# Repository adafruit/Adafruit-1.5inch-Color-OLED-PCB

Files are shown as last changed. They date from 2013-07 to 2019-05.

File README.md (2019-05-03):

# PCB for the Adafruit 1.5" Color OLED display breakout board

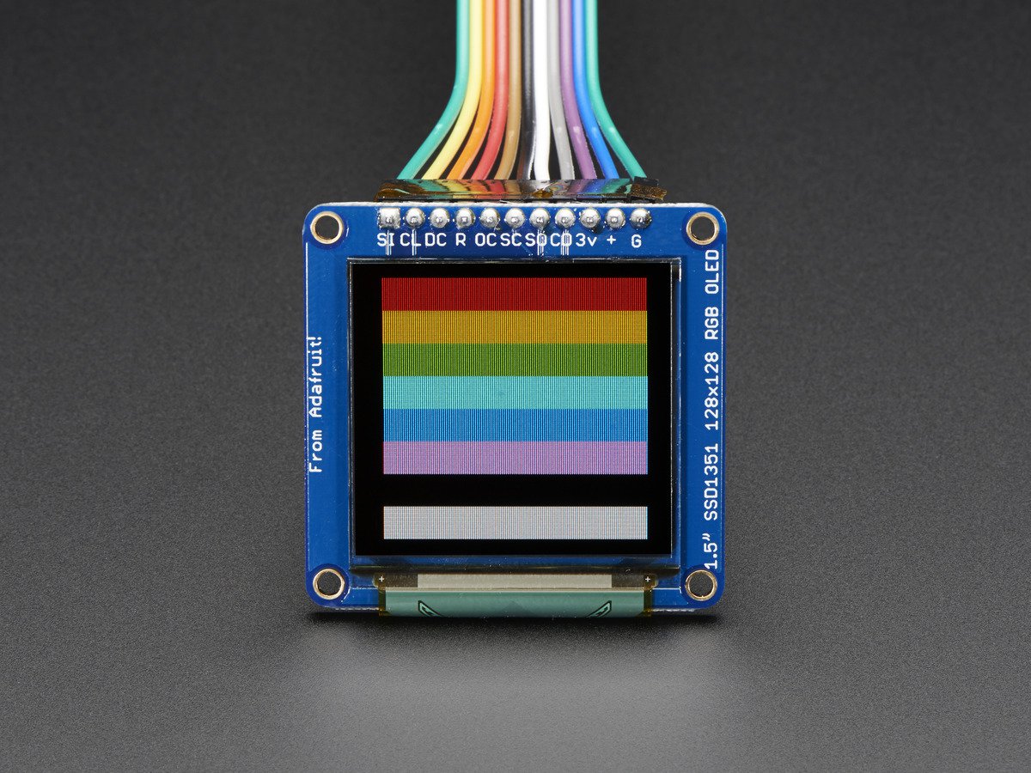
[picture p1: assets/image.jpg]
<a href="http://www.adafruit.com/products/1431"><br/>Click here to purchase one from the Adafruit shop</a>

This is the PCB for the Adafruit 1.5" Color OLED display breakout board
Format is EagleCAD schematic and board layout

We love our black and white monochrome displays but we also like to dabble with some color now and then. Our big 1.5" color OLED displays are perfect when you need a small display with vivid, high-contrast 16-bit color. The visible portion of the OLED measures 1.5" diagonal and contains 128x128 RGB pixels, each one made of red, green and blue OLEDs. Each pixel can be set with 16-bits of resolution for a large range of colors. Because the display uses OLEDs, there is no backlight, and the contrast is very high (black is really black). We picked this display for its excellent color, this is the nicest mini OLED we could find!

This OLED uses the SSD1351 driver chip, which manages the display. You can talk to the driver chip using 4-wire write-only SPI (clock, data, chip select, data/command and an optional reset pin). Included on the fully assembled breakout is the OLED display and a small boost converter (required for providing 12V to the OLED) and a microSD card holder. This design includes built-in logic level shifting so you can use it with 3-5VDC power and logic levels. Our example code shows how to read a bitmap from the uSD card and display it all via SPI.

Of course, we wouldn't just leave you with a datasheet and a "good luck!" - [we've written a full open source graphics library that can draw pixels, lines, rectangles, circles, text and bitmaps as well as example code](https://github.com/adafruit/Adafruit-SSD1351-library). The code is written for Arduino but can be easily ported to your favorite microcontroller! We do not have a detailed wiring tutorial at this time, but if you follow the example code wiring it should work just fine.

## License

Adafruit invests time and resources providing this open source design, 
please support Adafruit and open-source hardware by purchasing 
products from Adafruit!

Designed by Adafruit Industries.  
Creative Commons Attribution, Share-Alike license, check license.txt for more information
All text above must be included in any redistribution

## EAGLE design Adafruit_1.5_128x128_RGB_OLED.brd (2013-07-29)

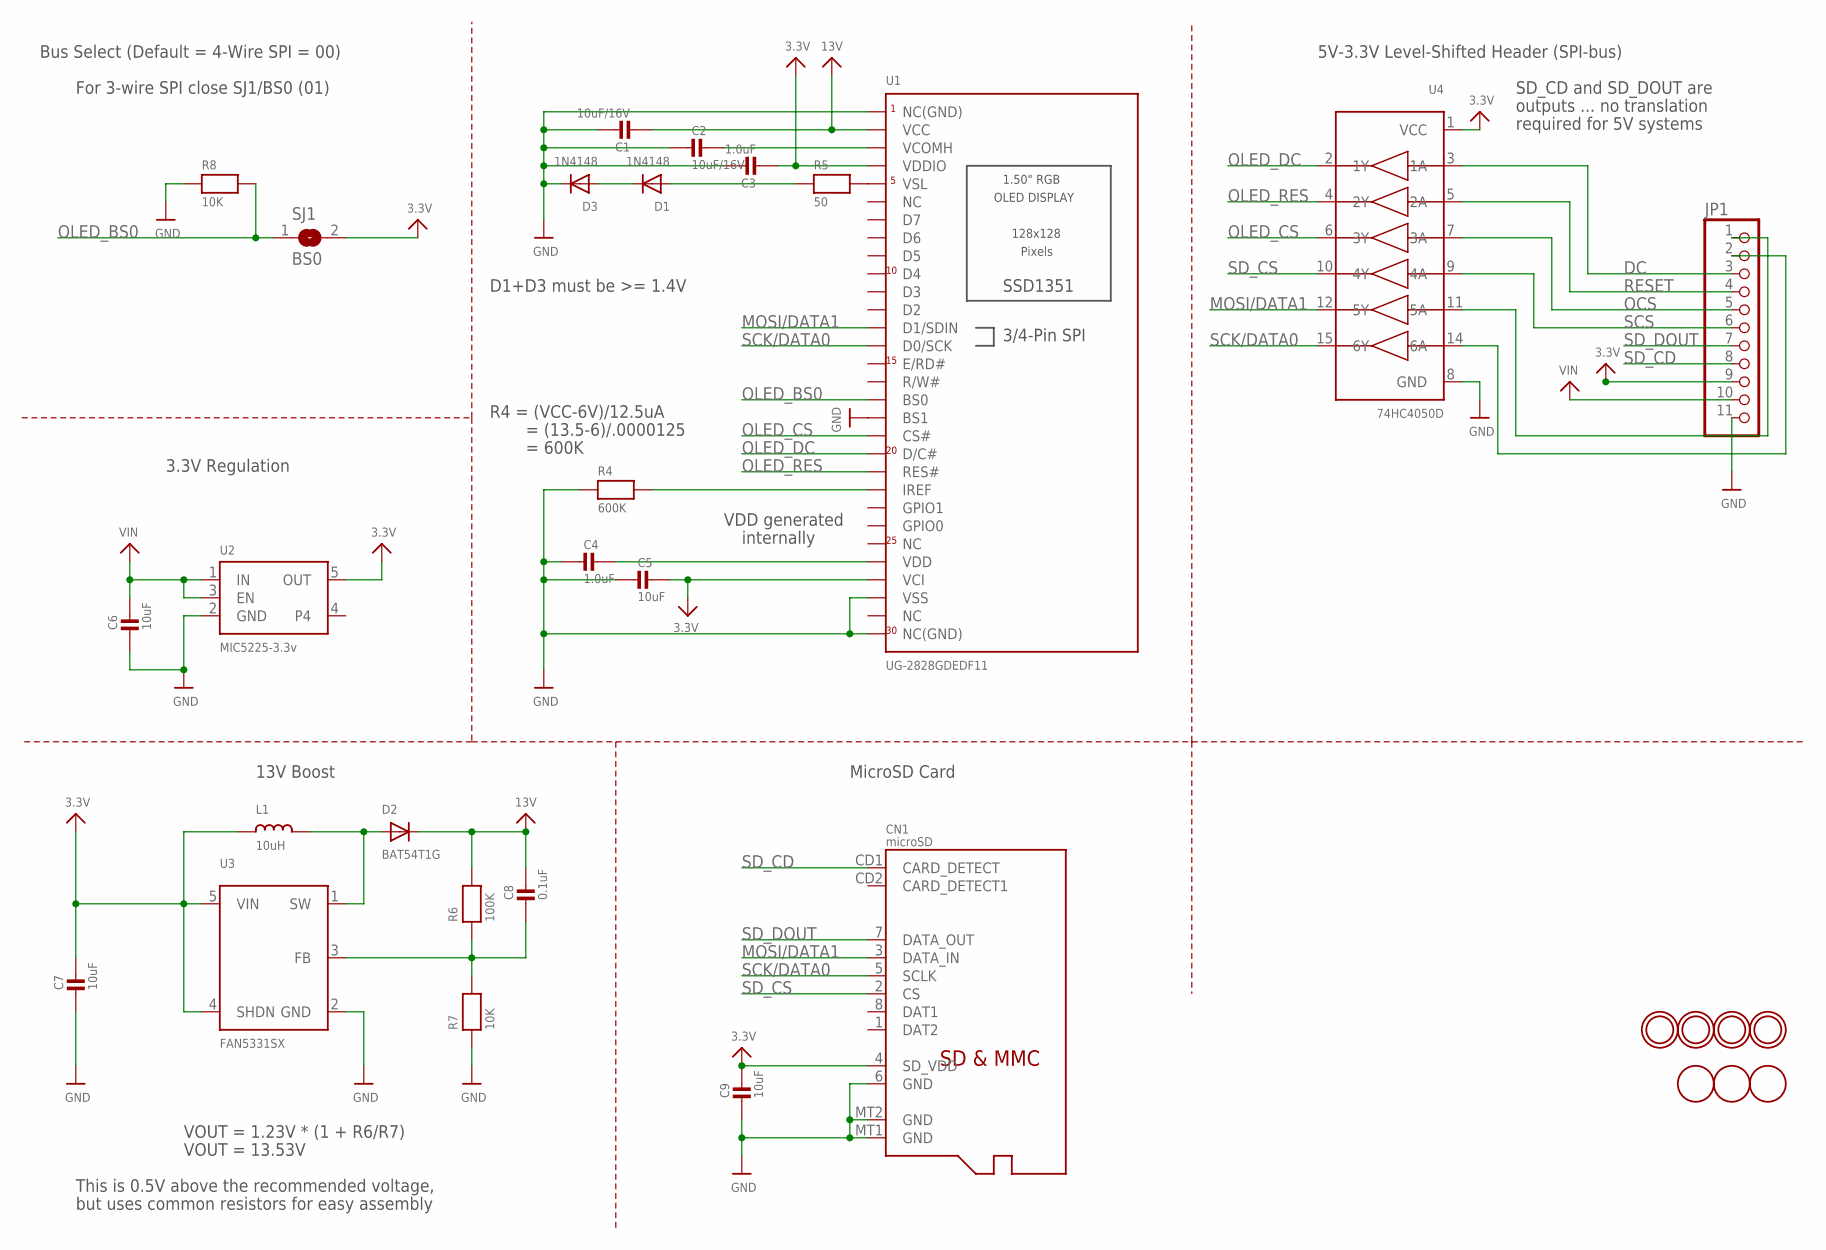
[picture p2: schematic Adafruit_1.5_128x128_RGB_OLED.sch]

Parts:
C1, C2: 10uF/16V; 0805
C3, C4: 1.0uF; 0805
C5, C6, C7, C9: 10uF; 0805
C8: 0.1uF; 0805
CN1: microSD; MICROSD
D1, D3: 1N4148; SOD-323
D2: BAT54T1G; SOD-123
JP1: HEADER-1X1176MIL; 1X11_ROUND_76
L1: 10uH; INDUCTOR_1007
R4: 600K; 0805
R5: 50; 0805
R6: 100K; 0805
R7, R8: 10K; 0805
SJ1: BS0; SOLDERJUMPER_REFLOW_NOPASTE
U1: UG-2828GDEDF11; FPC_XF2M-3015-1A
U2: MIC5225-3.3v; SOT23-5
U3: FAN5331SX; SOT23-5@1
U4: 74HC4050D; SOIC16
U$22, U$23, U$24, U$25: MOUNTINGHOLE2.5; MOUNTINGHOLE_2.5_PLATED
U$26, U$27, U$29: FIDUCIAL; FIDUCIAL_1MM

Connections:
3.3V: C3.2, C5.1, C7.1, C9.1, CN1.4 (SD_VDD), JP1.9, L1.P$1 (1), SJ1.2, U1.P$4 (VCI), U1.P$27 (VDDIO), U2.5 (OUT), U3.4 (SHDN), U3.5 (VIN), U4.1 (VCC)
13V: C1.2, C8.1, D2.C, R6.2, U1.P$29 (VCC)
DC: JP1.3, U4.3 (1A)
GND: C1.1, C2.2, C3.1, C4.2, C5.2, C6.2, C7.2, C9.2, CN1.6 (GND), CN1.MT1 (GND), CN1.MT2 (GND), D3.C, JP1.11, R4.1, R7.1, R8.1, U1.P$1 (NC(GND)), U1.P$3 (VSS), U1.P$13 (BS1), U1.P$30 (NC(GND)), U2.2 (GND), U3.2 (GND), U4.8 (GND)
IREF: R4.2, U1.P$9 (IREF)
MOSI/DATA1: CN1.3 (DATA_IN), U1.P$18 (D1/SDIN), U4.12 (5Y)
unnamed: C4.1, U1.P$5 (VDD)
unnamed: D2.A, L1.P$2 (2), U3.1 (SW)
unnamed: R5.2, U1.P$26 (VSL)
unnamed: D1.A, R5.1
unnamed: C8.2, R6.1, R7.2, U3.3 (FB)
unnamed: D1.C, D3.A
unnamed: JP1.1, U4.11 (5A)
unnamed: JP1.2, U4.14 (6A)
OCS: JP1.5, U4.7 (3A)
OLED_BS0: R8.2, SJ1.1, U1.P$14 (BS0)
OLED_CS: U1.P$12 (CS#), U4.6 (3Y)
OLED_DC: U1.P$11 (D/C#), U4.2 (1Y)
OLED_RES: U1.P$10 (RES#), U4.4 (2Y)
RESET: JP1.4, U4.5 (2A)
SCK/DATA0: CN1.5 (SCLK), U1.P$17 (D0/SCK), U4.15 (6Y)
SCS: JP1.6, U4.9 (4A)
SD_CD: CN1.CD1 (CARD_DETECT), JP1.8
SD_CS: CN1.2 (CS), U4.10 (4Y)
SD_DOUT: CN1.7 (DATA_OUT), JP1.7
VCOMH: C2.1, U1.P$28 (VCOMH)
VIN: C6.1, JP1.10, U2.1 (IN), U2.3 (EN)

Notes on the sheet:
Bus Select (Default = 4-Wire SPI = 00)
3.3V Regulation
VOUT = 1.23V * (1 + R6/R7)
VOUT = 13.53V
This is 0.5V above the recommended voltage,
but uses common resistors for easy assembly
13V Boost
MicroSD Card
For 3-wire SPI close SJ1/BS0 (01)
5V-3.3V Level-Shifted Header (SPI-bus)
SD_CD and SD_DOUT are
outputs ... no translation
required for 5V systems
R4 = (VCC-6V)/12.5uA
= (13.5-6)/.0000125
= 600K
D1+D3 must be >= 1.4V
VDD generated
internally

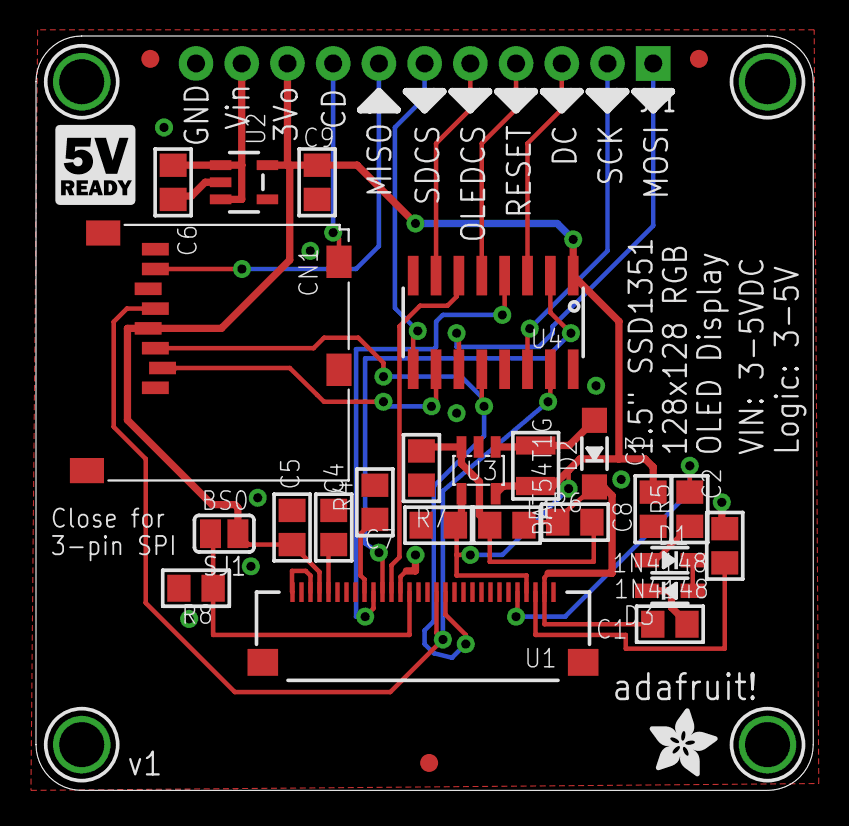
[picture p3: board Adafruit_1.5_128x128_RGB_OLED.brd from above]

Board: 2 copper layers, 43.2 x 41.9 mm, 34 parts (0 on the bottom side), 27 nets.

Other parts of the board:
U$28: ADAFRUIT_3.5MM
U$30: LOGIC_5VREADY_5MM
